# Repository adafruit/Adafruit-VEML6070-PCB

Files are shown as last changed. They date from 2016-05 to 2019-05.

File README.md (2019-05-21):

## Adafruit VEML6070 Sensor PCB
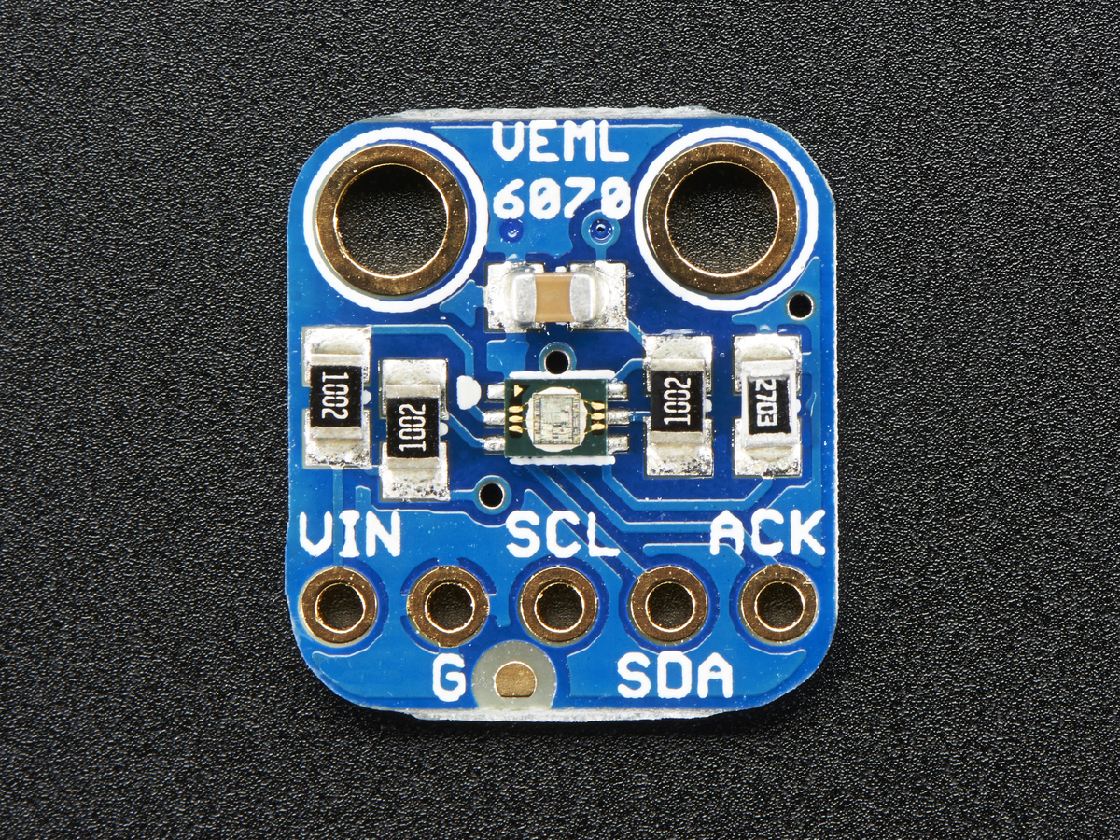
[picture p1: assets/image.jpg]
<a href="http://www.adafruit.com/products/2899"><br/>
Click here to purchase one from the Adafruit shop</a>

This little sensor is a great way to add UV light sensing to any microcontroller project. The VEML6070 from Vishay has a true UV A light sensor and an I2C-controlled ADC that will take readings and integrate them for you over ~60ms to 500ms.

Please note, for UV sensing we now recommend the VEML6075 which is an improved version of this sensor with both UVA and UVB sensors and UV Index calculations

Unlike the Si1145, this sensor will not give you UV Index readings. However, the Si1145 does UV Index approximations based on light level not true UV sensing. The VEML6070 in contrast does have a real light sensor in the UV spectrum. It's also got a much much simpler I2C interface so you can run it on the smallest microcontrollers with ease. Unlike the GUVA analog sensor, the biasing and ADC is all internal so you don't need an ADC.

This UV sensor works great with 3 or 5V power or logic, its nice and compact, and its easy to use with any I2C-capable microcontroller. Each order comes with one assembled PCB with a sensor, some handy pullup resistors, a 270K rset resistor and a small piece of header. Some light soldering is required to attach the header but its a fast task!

PCB files for Adafruit VEML6070 sensor breakout. The format is EagleCAD schematic and board layout
- https://www.adafruit.com/product/2899

### License

Adafruit invests time and resources providing this open source design, please support Adafruit and open-source hardware by purchasing products from [Adafruit](https://www.adafruit.com)!

All text above must be included in any redistribution

Designed by Limor Fried/Ladyada for Adafruit Industries.
Creative Commons Attribution/Share-Alike, all text above must be included in any redistribution. 
See license.txt for additional information.

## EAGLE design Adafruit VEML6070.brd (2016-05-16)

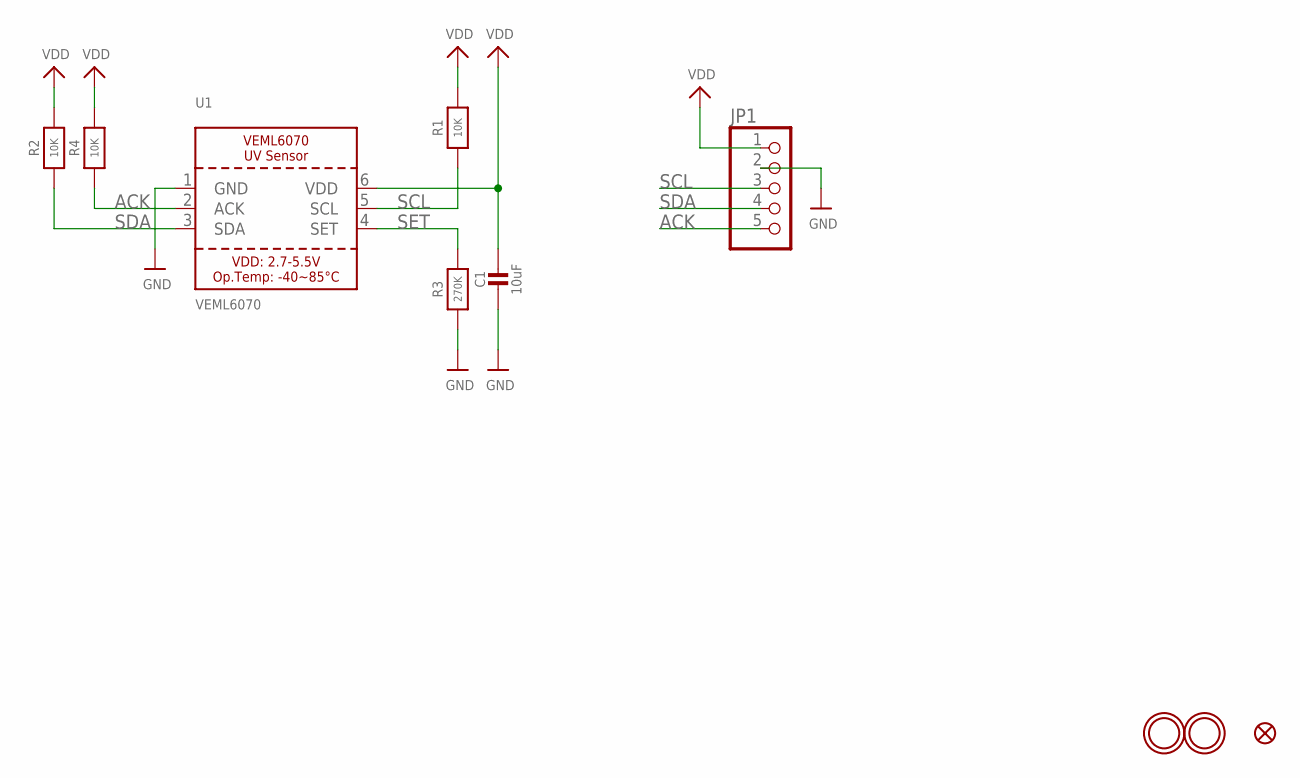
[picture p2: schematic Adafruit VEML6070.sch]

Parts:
C1: 10uF; 0805-NO
FID1: FIDUCIAL""; FIDUCIAL_1MM
JP1: HEADER-1X570MIL; 1X05_ROUND_70
R1, R2, R4: 10K; 0805-NO
R3: 270K; 0805-NO
U1: VEML6070
U$10, U$11: MOUNTINGHOLE2.5; MOUNTINGHOLE_2.5_PLATED

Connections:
ACK: JP1.5, R4.1, U1.2 (ACK)
GND: C1.2, JP1.2, R3.1, U1.1 (GND)
SCL: JP1.3, R1.1, U1.5 (SCL)
SDA: JP1.4, R2.1, U1.3 (SDA)
SET: R3.2, U1.4 (SET)
VDD: C1.1, JP1.1, R1.2, R2.2, R4.2, U1.6 (VDD)

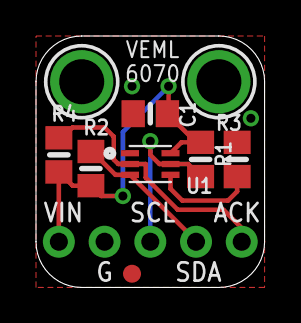
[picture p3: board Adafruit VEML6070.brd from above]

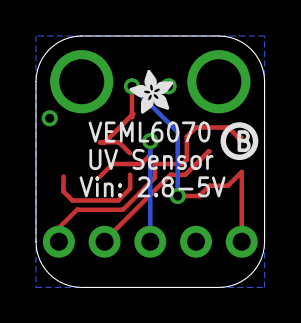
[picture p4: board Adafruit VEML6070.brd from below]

Board: 2 copper layers, 12.7 x 14.0 mm, 12 parts (2 on the bottom side), 6 nets.

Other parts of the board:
U$2: PCBFEAT-REV-040
U$14: ADAFRUIT_2.5MM

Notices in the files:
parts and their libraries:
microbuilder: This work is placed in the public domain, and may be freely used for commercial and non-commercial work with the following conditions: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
